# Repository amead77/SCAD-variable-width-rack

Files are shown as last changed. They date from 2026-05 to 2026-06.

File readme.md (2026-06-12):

# Variable width Rack design.

No longer are you stuck with 10" rack or a 19" rack you can't print parts for! What's more, you can actually have supported trays :)

Normal defaults are 350mm wide panel, 330mm deep tray. (this can be changed)

So, what is this actually?
Simply put, I wanted a bigger rack that I could print on my Creality K2plus (350x350x350 build volume) and I wanted it to be 100% in OpenSCAD. Because that's the only software I can use. Fusion 360 is good, but eats cpu, doesn't work on Linux, and worst of all, they changed the licence and features available for hobbyists.
What about FreeCAD? Yeah, FreeCAD is getting good now, but I just didn't want to learn it, because that would require starting out with the spec nailed down before even creating a design. It wasn't at the start.

One of the biggest reasons for creating it was also anger. I printed the parts for a 10" mini rack because I was prepared to make do. But the design was such that to remove a tray, you need to dismantle the whole thing, because of the way the trays are secured at the rear.

There is a picture of the mini-rack that made me angry at the bottom of this readme.

Anyway, if you like the design, you're welcome to buy me a coffee:

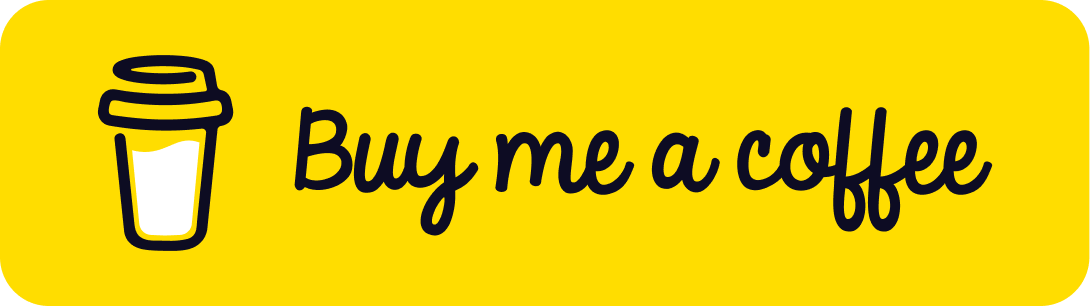
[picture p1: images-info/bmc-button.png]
Buy Me a Coffee


A quick overview

Below is a screenshot of OpenSCAD with a assembly view. This is just to show an example of some of what is possible. Everything is customisable.

## For API reference see [functions.md](functions.md)

I've numbered some arrows so you can see:

1. is showing top header, this is an extra hole added to the post for joining to 2. These  are not required if you don't want stability.
2. is the top join, this joins the posts together at the top. Note: you can have 4 OR MORE posts. I have 6 in this example and how I use it. They can optionally (recommended) have the support cones. This is so the posts can lock in place if they also have cones.
3. A half U panel. Technically not half-U, but that's what I called it. This is used to span across the posts and secure the top and bottom joins.
4. The bottom join. Just like the top.
5. Here is where you put post joins. These are a little square section that joins the inner posts to the top/bottom joins. Otherwise they'd be floating.
6. A side panel. In my case I made a honeycome panel and added a raspberry pi logo.

Note: For mine I used 6 posts (great for half depth trays), 4 face forward, rear 2 face backwards. Consider this when creating posts for which side you want the side-slides on.

2026-06-08: For ease of printing, I've modified:
- Tray design to default to single support rail per-U, as in practice 3 per-U was overkill.
- Split tray into a panel and tray actual, with a joining part added to both with screw holes. I just shoved normal wood screws in mine as that's what I had. (heated them first, so they bind in when cooled)
- Increased the tolerances as in practice printing in different directions with/without support has an effect.

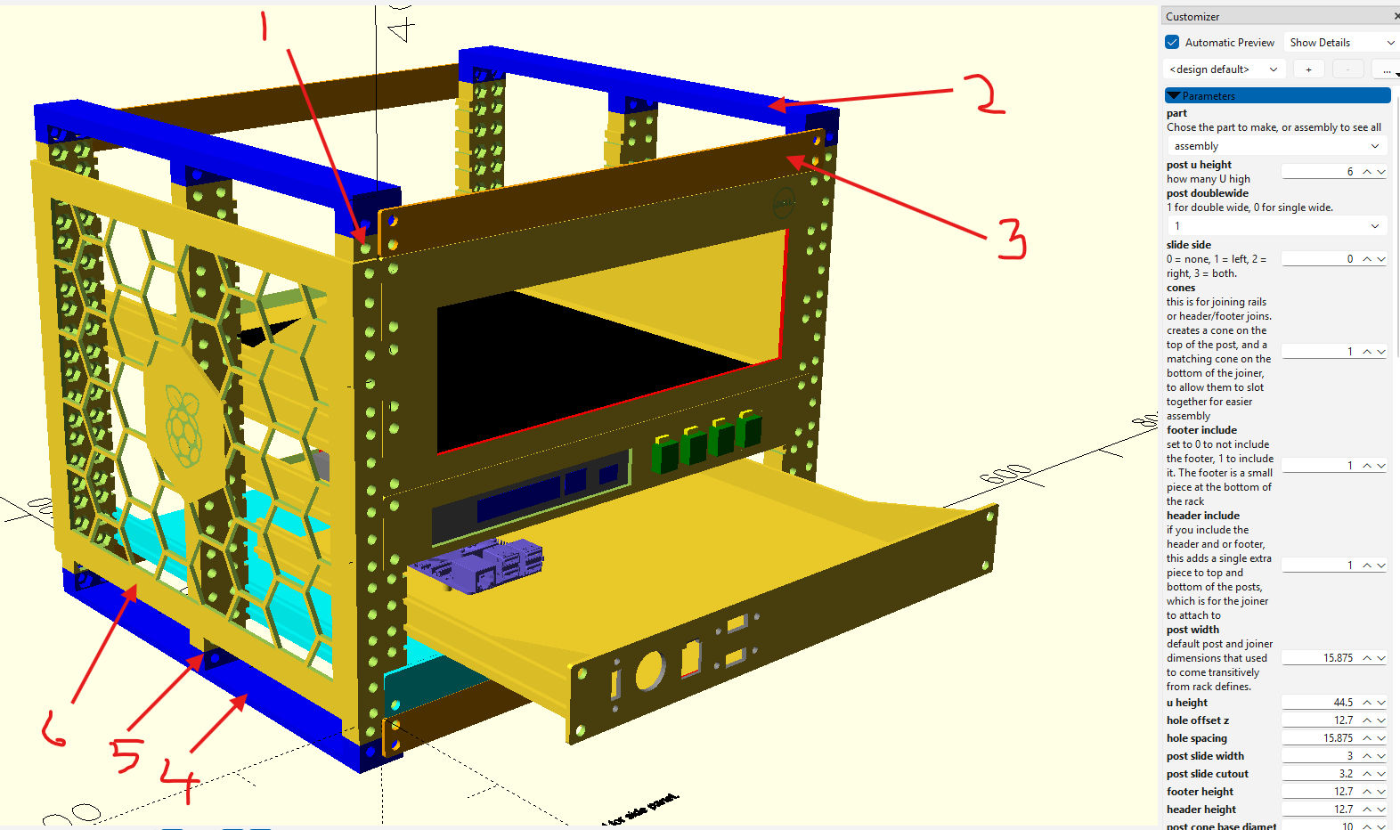
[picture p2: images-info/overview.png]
Assembly overview


Rear view

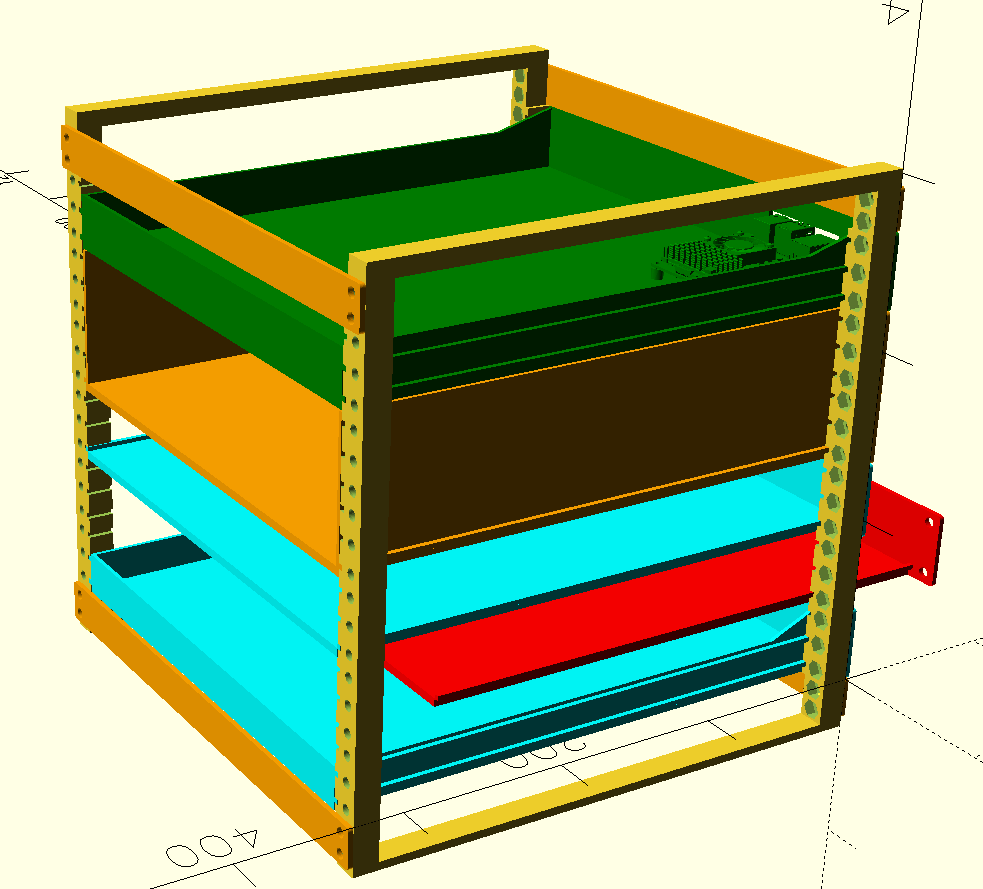
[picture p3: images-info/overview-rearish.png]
Rear view of assembly


8 legged freak

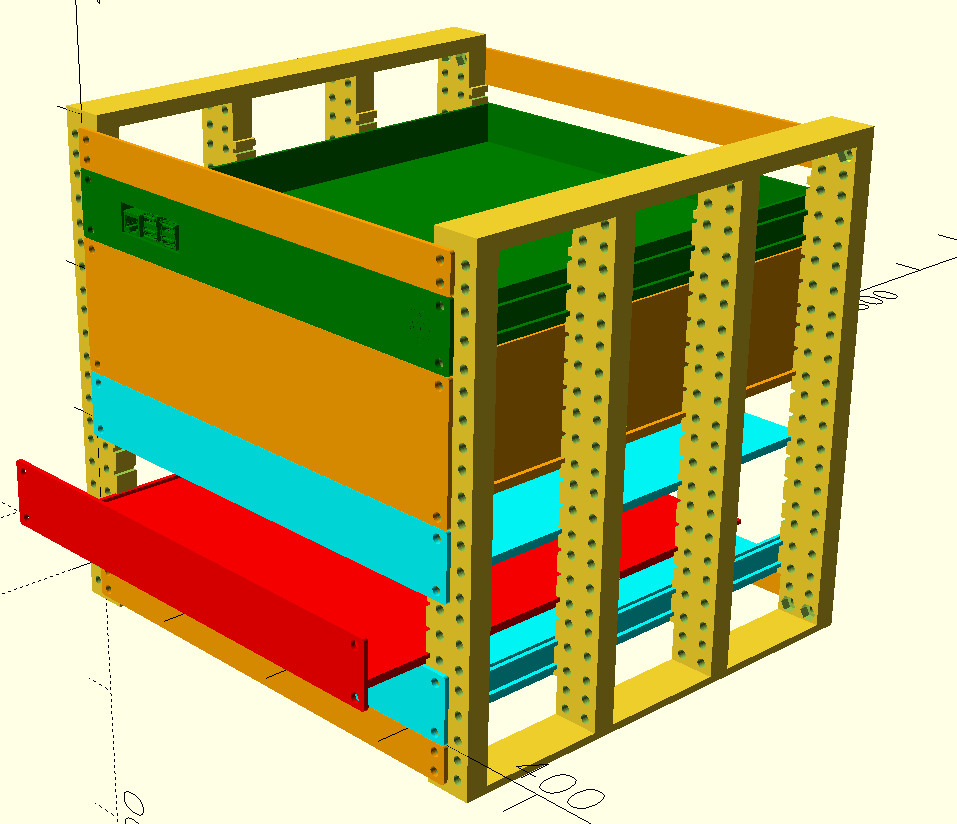
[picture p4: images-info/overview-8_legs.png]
Assembly with 8 legs


How about a part complete rack, as in.. mine. I do have a tray for the Dell, but haven't printed it yet, so the Dell is just thrown in there. It is not a good computer, it is old but it was free.

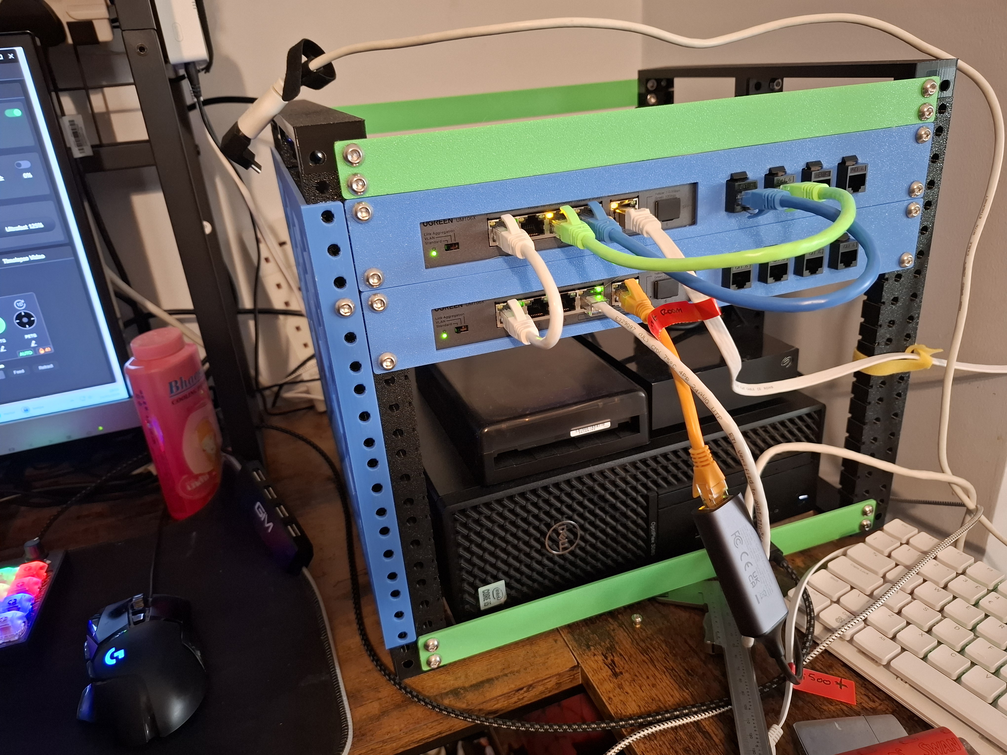
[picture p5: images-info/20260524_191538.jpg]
dell


Now the side panel. You don't have to have honeycomb, you can have a few different designs, plus size of shapes, image/logo is also optional. I have a RPi logo because I have a bunch of them. They'll end up in the rack in due course.

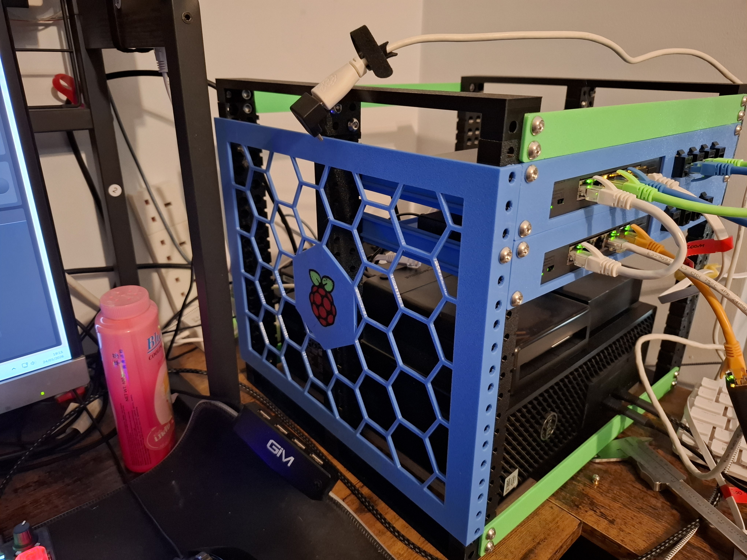
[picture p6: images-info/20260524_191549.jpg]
side panel


---

## Design Goals

- **Rear-slide tray support** — trays slide into a slot in the rear post rather than bolting front and rear. This means trays can be removed without dismantling the rack. This was my biggest gripe with the 10" rack designs.
- **Fully parametric** — all dimensions, hole counts, heights and clearances are driven by variables. Use the OpenSCAD Customizer to configure parts without editing code.
- **Modular** — mix single/double-wide posts, variable-height trays and panels, and optional joiners.

---

## Parts

### Posts

Posts are the vertical rails of the rack. They are generated in configurable U heights and can be single or double wide. A slide channel can be added to the left side, right side, both sides, or neither. 
I highly recommend creating with top/bottom headers, double-wide, cones and side slides. 

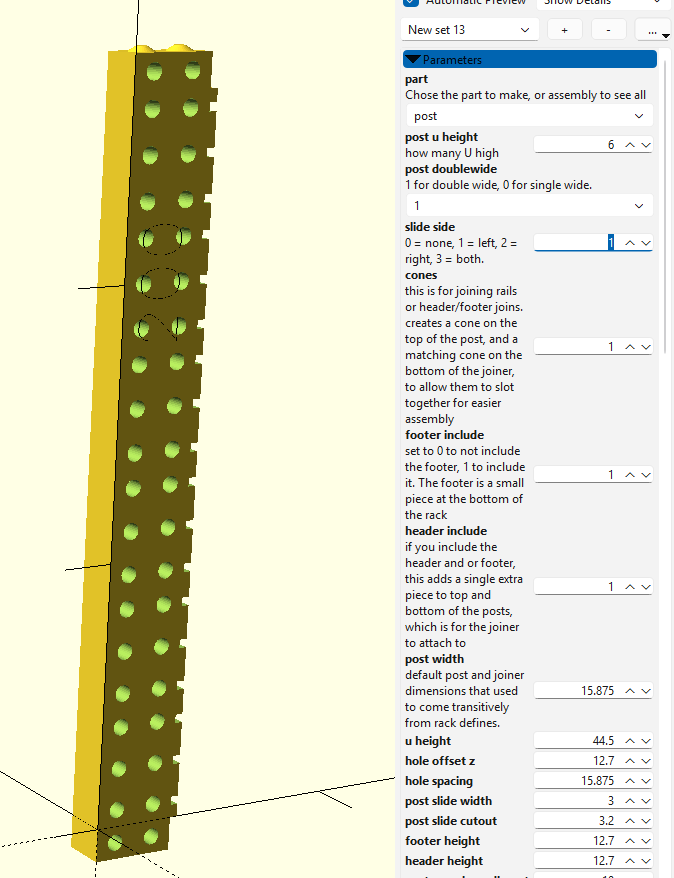
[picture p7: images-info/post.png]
Post


### Trays

Trays are available in fully variable size. The variable tray accepts a `tray_back_panel` flag to add a rear panel, turning it into a drawer. Trays slide into the post's rear slot for easy removal. Trays also don't need to be full length, defining 0.25 will make a quarter depth tray (y axis)

Look at "parts/blank variable tray.scad" to find the tray code, but "parts-optional/intel dg45fg.scad" shows it being used.
More info on how to use later.

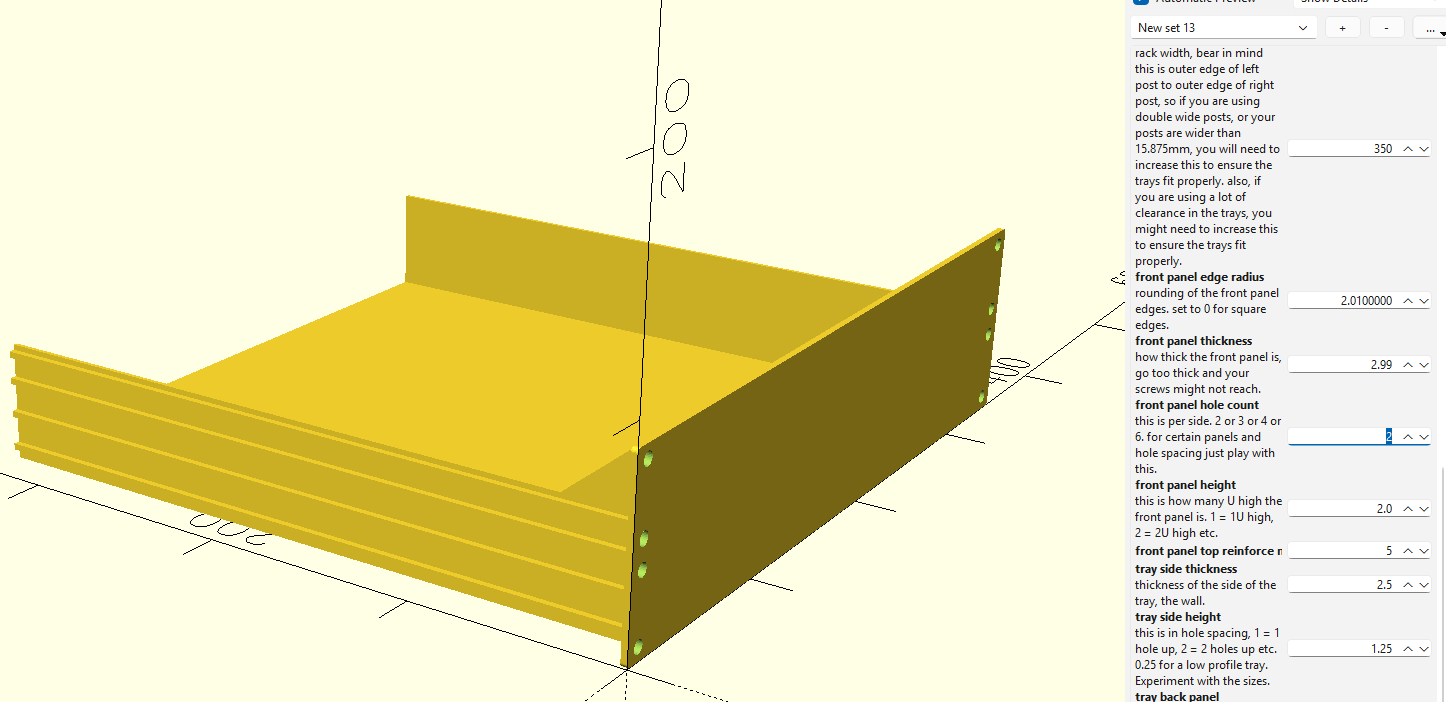
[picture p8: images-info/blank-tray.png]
Variable tray


You can also split the trays for easier printing.

ts1

ts2

ts3

### Panels (Blanking Panels)

"parts/rack panels.scad"

Flat front panels for blanking unused rack slots. Available in ½U, 1U, 2U.
Note that "blank variable tray" can now do all of this apart from the half-U. It is also the recommended method as you can customise it, reinforce, etc.

The half-U for joining posts together when using headers.

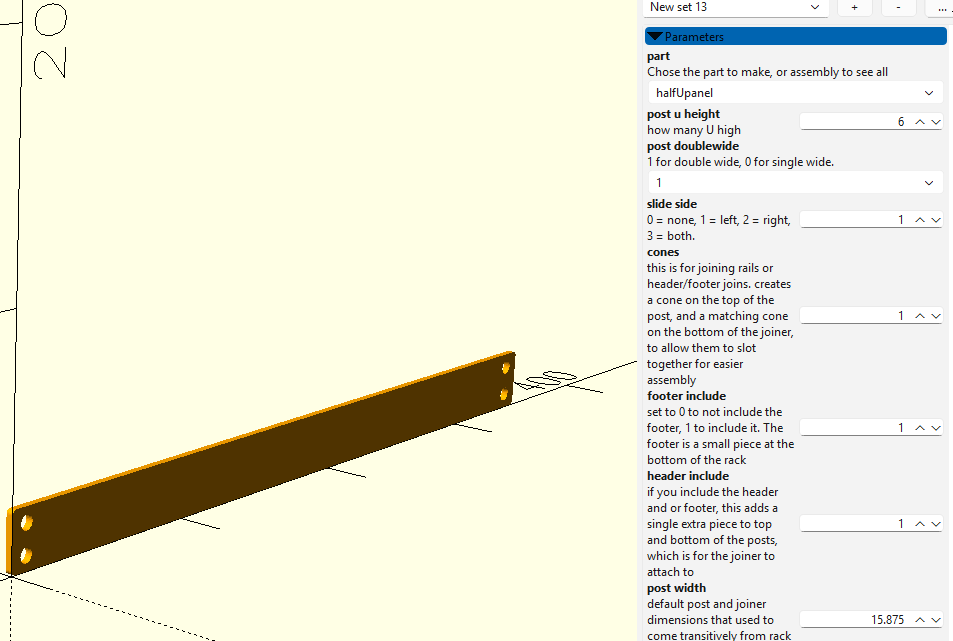
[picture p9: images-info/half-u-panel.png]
Half-U panel


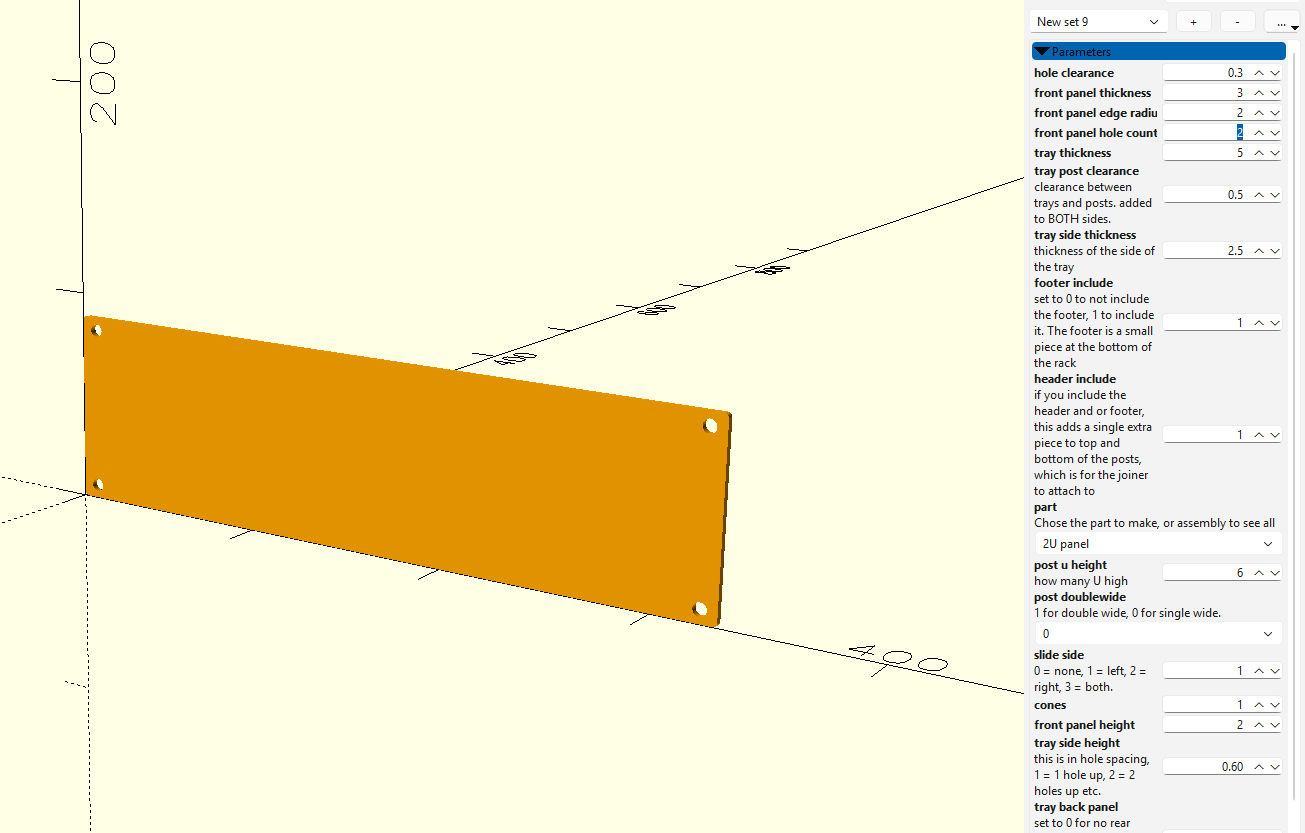
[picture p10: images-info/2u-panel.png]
2U panel


### Footer / Header

Optional pieces added to the top and bottom of POSTS. They provide an attachment point for the joiners.
If you want the front to rear support braces, I recommend adding these on.

### Joiners (Base / Top)

Optional horizontal joiners that connect the front posts to the rear posts via the footer/header. 
You can have more than just 4 posts. The joiners can have 2+ supports, by increasing the number and printing more posts, you can have greater supports

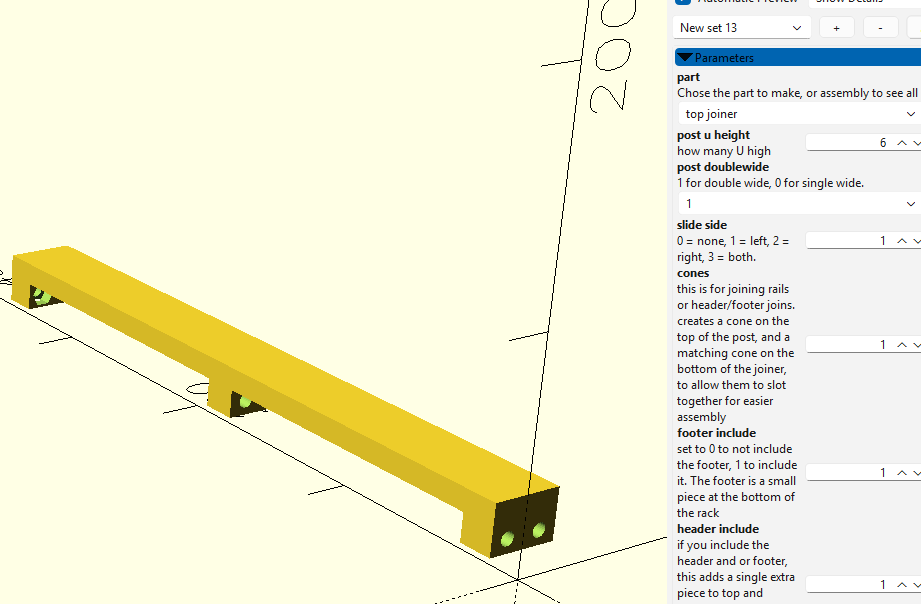
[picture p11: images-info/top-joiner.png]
Top joiner


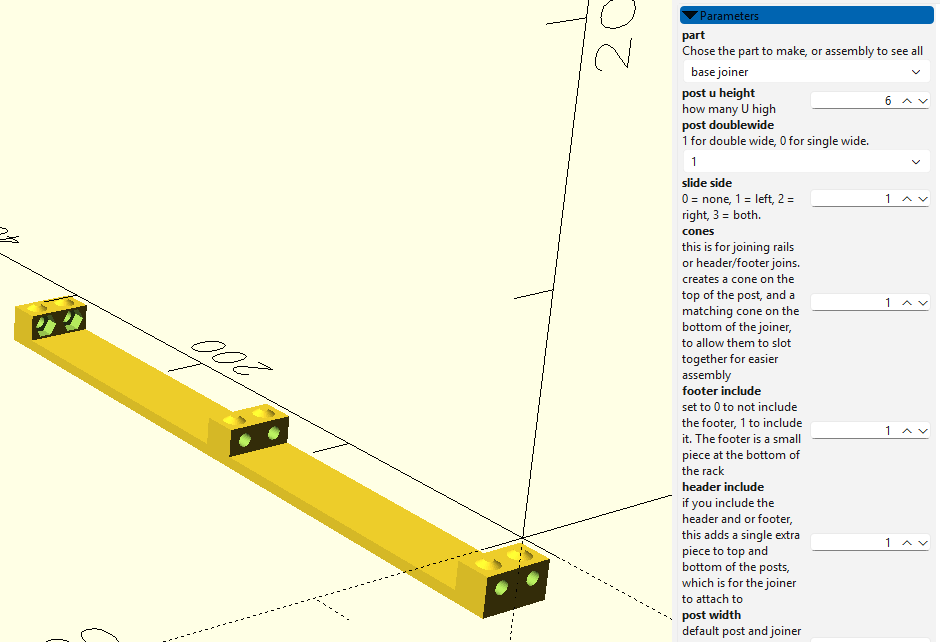
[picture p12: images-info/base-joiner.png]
Base joiner


---

## Custom Trays

The file "parts-optional/intel dg45fg.scad" has a tray I've made for my mini-itx board. Yes it's an older board, this is because I want it for WinXP.
Anyway, it has:
- mount for a FlexATX PSU
- screw holes for mini-itx, for the back panel to be on the rear. (screw holes are sized for my heat-inserts)
- a LED hole in the front for hdd activity
- a Power button (large round) cutout
- Name of board/cpu inside on the front of the panel. (I use a engrave of 0.01mm, this makes it easy to 'paint' in my slicer, while still being level with the panel)
- reinforced front panel at the top
- reinforced rear, by creating a back panel, then chamfering it at 30deg. this is because I print panel face down and it means far less supports
- If my printer wasn't being a D. I'd have it printed by now. 

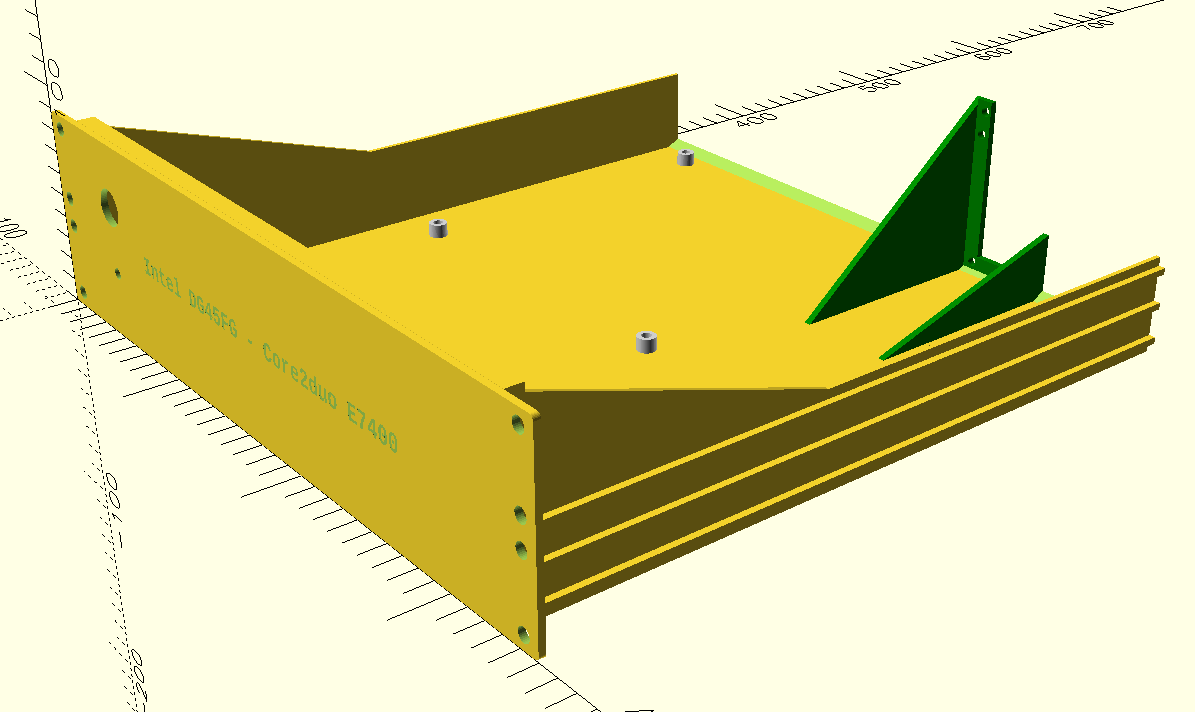
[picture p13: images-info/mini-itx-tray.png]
mini-itx


This picture is the mini-itx tray, but I chopped it to a tiny piece in the slicer, I highly recommend making test pieces before commiting to 12hour+ prints. Even create 1U post with sliders and a part tray to check clearances. Everyone's printer is different.

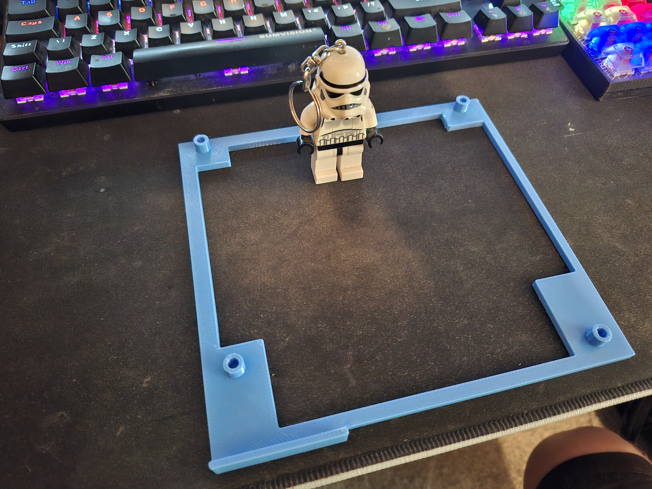
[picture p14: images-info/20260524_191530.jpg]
test print


When I fix my printer I will print the mini-itx tray like the following picture, note that:
- I chop out parts to reduce filament usage. I do the chopping in the slicer by adding negative volumes.
- angle the cutouts so they don't require supports.
- print face down so the support rails don't require supports.
- print face down so my text on the front panel gets printed in one hit on a single layer, rather than changing filament many many times.
- created a back panel, but only small and use a 30 degree chamfer. This is to create a reinforcement that doesn't require supports to print
- Doing it this way means only the PSU mount and mini-itx screw holes need supports.

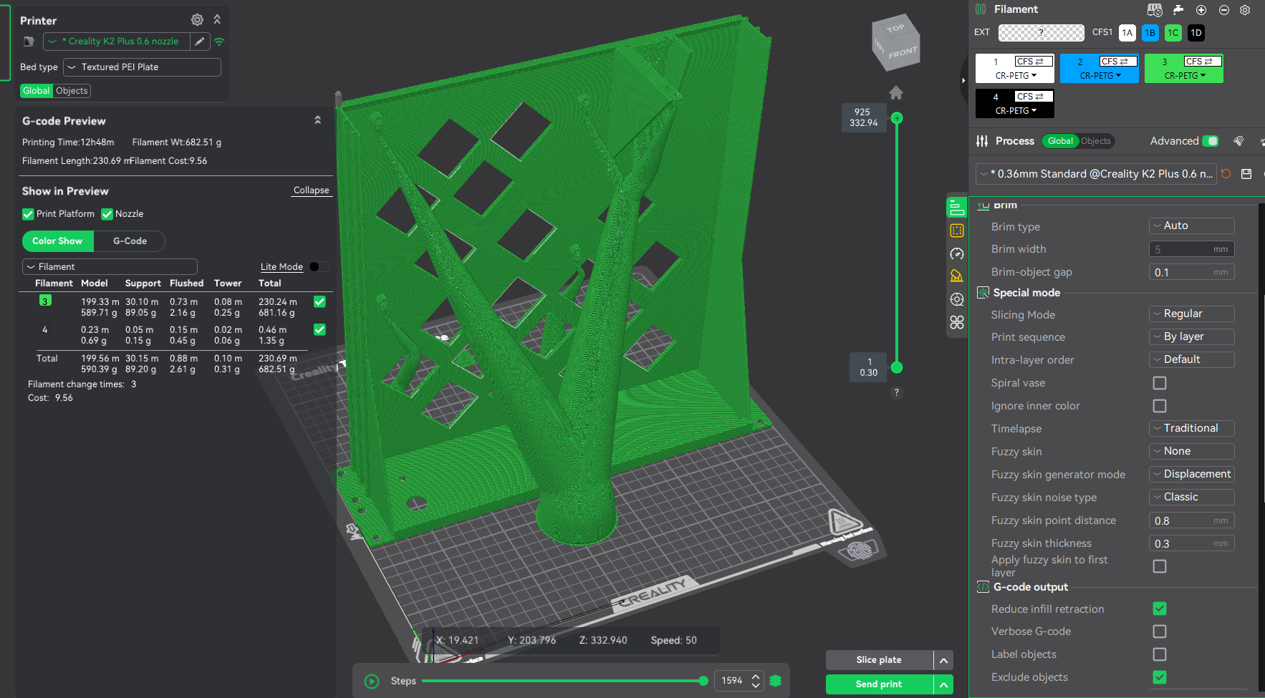
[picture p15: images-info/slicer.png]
slicer


The file "parts-optional/ugreen um106x.scad" is another one I use (x2), and have a photo of in use.
This was created to:
- have my 5 port switch
- 4x keystones

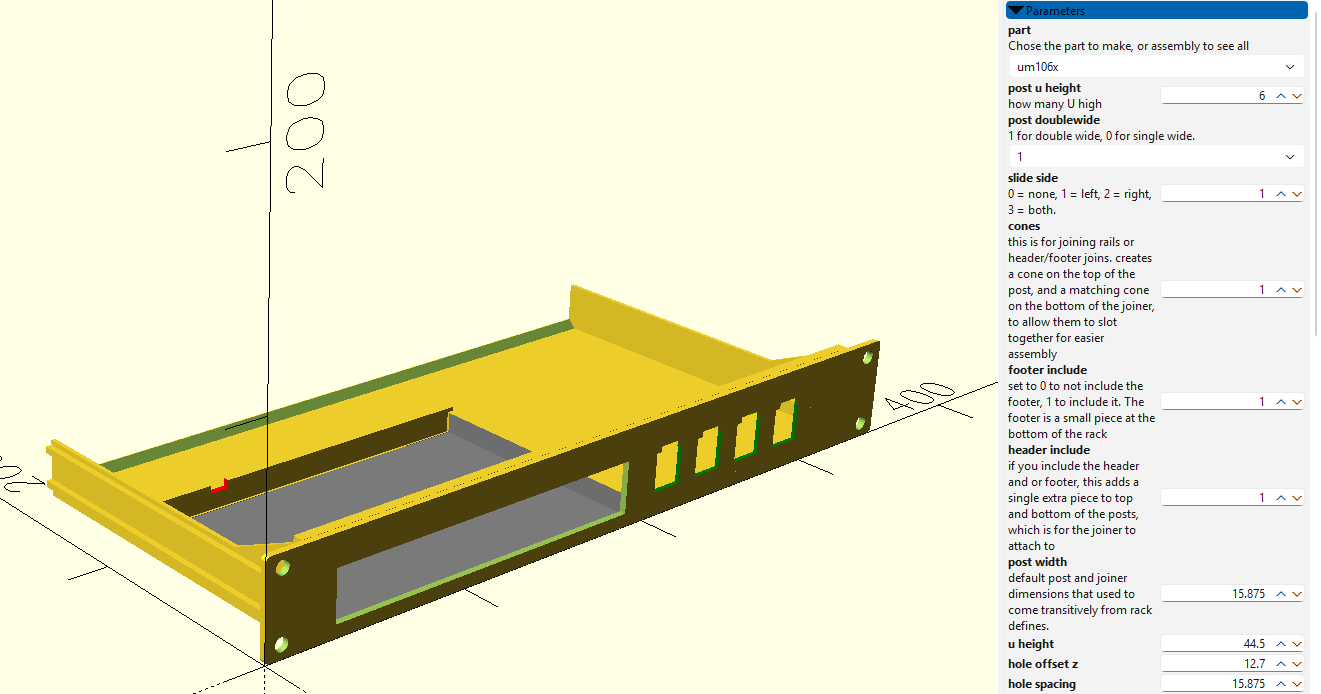
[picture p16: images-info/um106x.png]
ugreen


---

## Usage

1. Open `rack parts.scad` in OpenSCAD. This is not perfect. This will create the basic parts, but not highly customised trays.
2. Open the **Customizer** panel (Window → Customizer).
3. Select the part you want from the `part` dropdown:
   - `assembly` — preview all parts together
   - `post` — a single post, I recommend double-wide for future side panels etc, and slide_sides, if you want the trays to be supported.
   - `base joiner` / `top joiner` — horizontal joiners, also recommended. Make sure your posts have headers/footers and cones.
   - `1U tray` / `2U tray` / `variable tray` — trays
   - `halfUpanel` / `1U panel` / `2U panel` / `variable panel` — blanking panels
4. Adjust the parameters to suit your needs.
5. Render (F6) and export to STL or 3MF

### Key Parameters

| Parameter | Description |
|---|---|
| `post_u_height` | Height of the post in U units |
| `post_doublewide` | `0` = single wide, `1` = double wide |
| `slide_side` | `0` none, `1` left, `2` right, `3` both |
| `front_panel_height` | Panel/tray height in U (can be fractional, e.g. `1.5`) |
| `front_panel_hole_count` | Mounting holes per side (2, 3, 4, or 6) |
| `tray_side_height` | Tray side wall height in hole spacings |
| `tray_back_panel` | `0` = open tray, `1` = drawer with rear panel |
| `footer_include` / `header_include` | Include footer/header attachment pieces |

### Hardware

The design is based on **M6 screws** with **M6 hex nuts** (10mm across-flats, 5mm thick). Adjust `hole_clearance`, `hole_d`, `nut_diameter`, and `nut_thickness` if you want to use different fasteners. See the comments in the posts and trays functions.

---

## File Structure

| File | Purpose |
|---|---|
| `rack parts.scad` | Main entry point — select and configure parts here |
| `parts/rack defines.scad` | All default dimensions and constants - DEPRECIATED, kept for reference|
| `parts/rack posts.scad` | Post geometry |
| `parts/rack panels.scad` | Panel geometry, for 0.5U, 1U and 2U |
| `parts-optional/intel dg45fg.scad` | My mini itx tray, useful for reference
| `parts/blank variable tray.scad` | The main tray and panel making scad. Call blank_variable_tray() for everything, then customise.
---

The reason parts/rack defines.scad is depreciated is because everything got refactored so that the default values of calling the functions are what was in the defines. Everything can be overriden in the function calls.
I really recommend having a look at the parts and how they are called, then look at the function/module they call, because I have commented all the options.

## Requirements

- [OpenSCAD](https://openscad.org/) the releases are ancient, use the nightlies instead. On raspberry pi you have to compile from source.
- A printer that can handle the size you want (e.g. Creality K2 Plus can do 350mm, Prusa XL can do 340mm)

---

## License

This project is licensed under **Creative Commons - Attribution - Non-Commercial (CC BY-NC)**

&copy; 2026 Adam Mead

All images of Raspberry Pi and Dell logos are their own. I have only included to prevent non existent file errors.

## THIS PIC IS NOT MY DESIGN, but I did print it and this is what it produced. It is the reason I made my design:

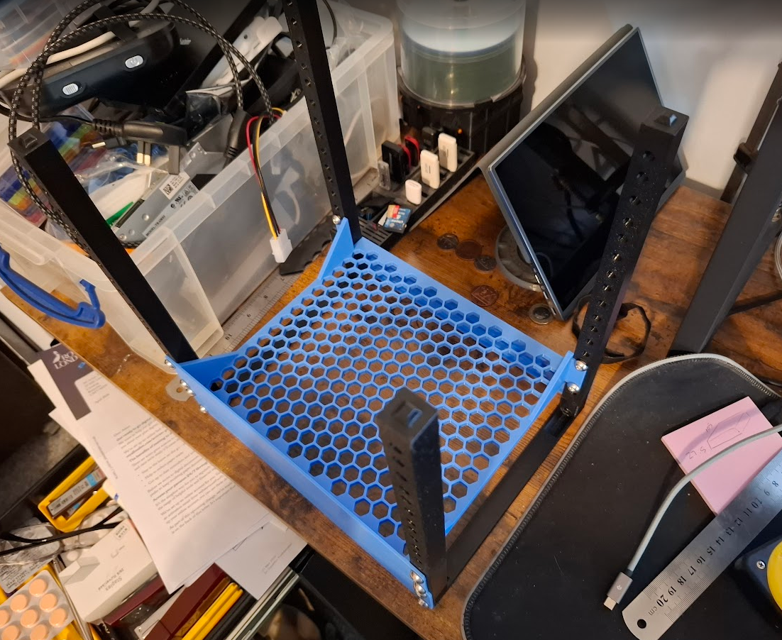
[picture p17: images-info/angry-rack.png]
angry rack


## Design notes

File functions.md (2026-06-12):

# Variable width Rack (default=350mm wide, 330mm deep) - Current Public Module Reference

This file documents the current public callable modules in the four core source files that are enough to build a working rack:

- `parts/rack posts.scad`
- `parts/rack panels.scad`
- `parts/rack side panel.scad`
- `parts/blank variable tray.scad`

If you are building a rack from scratch, the core structural parts are usually:

- `rail_1u_holes()` for posts
- `base_joiner()` for front-to-rear joiners
- `blank_05U_front_panel()` for the front and rear, top and bottom bridging panels - headers/footers to joiners
- `post_base_join_panel()` if you are using extra intermediate posts

Then add either:

- `blank_1U_front_panel()` / `blank_2U_front_panel()` / `blank_variable_tray(mode="panel")` for blanking panels
- `blank_variable_tray()` for trays
- `side_panel()` for optional side panels, adds +5 HP

---

## `parts/rack posts.scad`

### `rail_1u_holes()` - Complete rack post

Builds a complete rack post from stacked 1U sections, including screw holes, rear nut traps, optional slide rails, optional footer/header blocks, and optional alignment cones.

```scad
module rail_1u_holes(
    slide_side,                             // 0 = none, 1 = left, 2 = right, 3 = both side rails.
    doublewide = 0,                         // 0 = single-width post, 1 = double-width post.
    post_height = 3,                        // Post height in U units.
    v_post_cones = 1,                       // 1 = add top cones and bottom sockets, 0 = no cones.
    include_footer = 1,                     // 1 = include the lower footer block.
    include_header = 1,                     // 1 = include the upper header block.
    post_width = 15.875,                    // Width/depth of one post section.
    u_height = 44.5,                        // Height of one U section in mm.
    hole_d = 6.3,                           // Diameter of the post mounting holes.
    hole_offset_z = 12.7,                   // Height from the bottom of a 1U segment to the first hole centre.
    hole_spacing = 15.875,                  // Vertical spacing between hole centres within a 1U segment.
    nut_thickness = 6.3,                    // Depth of the rear nut traps.
    nut_diameter_across_flats = 10.3,       // Across-flats size of the hex nut trap.
    post_slide_width = 2.8,                 // Width of the side slide rail.
    post_slide_cutout = 3.6,                // Size of the slide cutouts in each 1U section.
    footer_height = 12.7,                   // Height of the optional footer block.
    header_height = 12.7,                   // Height of the optional header block.
    post_cone_base_diameter = 10.0,         // Diameter at the base of the alignment cone/socket.
    post_cone_top_diameter = 4.0,           // Diameter at the tip of the alignment cone/socket.
    post_cone_height = 2.0,                 // Height/depth of the alignment cone/socket.
    post_top_cone_clearance = 0.1           // Clearance applied so cones fit into sockets.
)
```

Examples:

```scad
rail_1u_holes(slide_side = 1, post_height = 6);
rail_1u_holes(slide_side = 3, doublewide = 1, post_height = 6, v_post_cones = 1);
```

### `base_joiner()` - Front-to-rear joiner

Builds the horizontal joiner that connects front and rear posts. Set `bottom=1` for the lower joiner and `bottom=0` for the upper joiner.

```scad
module base_joiner(
    doublewide = 0,                         // 0 = single-width post mount, 1 = double-width post mount.
    bottom = 1,                             // 1 = bottom/base joiner, 0 = top/header joiner.
    supports = 2,                           // Number of support positions along the joiner, minimum 2.
    beam_thickness = 5.0,                   // Thickness of the long beam that ties the support blocks together.
    post_width = 15.875,                    // Width of one post footprint.
    rack_width = 330,                       // Front-to-rear span used for the main joiner body layout.
    rack_depth = 330,                       // Front-to-rear span used by the mirrored top joiner cone cut positions.
    footer_height = 12.7,                   // Height of the footer-side mounting blocks.
    header_height = 12.7,                   // Height of the header-side mounting blocks or cone sockets.
    hole_offset_z = 12.7,                   // Vertical position of the joiner mounting hole centre.
    hole_d = 6.3,                           // Diameter of the joiner mounting screw holes.
    nut_thickness = 6.3,                    // Depth of the nut traps for the mounting fasteners.
    nut_diameter_across_flats = 10.3,       // Across-flats size of the hex nut trap.
    post_cone_base_diameter = 10.0,         // Diameter at the base of the alignment cone/socket.
    post_cone_top_diameter = 4.0,           // Diameter at the tip of the alignment cone/socket.
    post_cone_height = 2.0,                 // Height/depth of the alignment cone/socket.
    post_top_cone_clearance = 0.1           // Clearance applied so cones fit into sockets.
)
```

Examples:

```scad
base_joiner();
base_joiner(bottom = 0, beam_thickness = 10.0);
base_joiner(doublewide = 1, supports = 3, beam_thickness = 6.0);
```

---

## `parts/rack panels.scad`

### `blank_1U_front_panel()` - Fixed 1U blanking panel

Builds a standard 1U front blanking panel with the normal rack hole pattern.
*Variable tray* can also built panels and is the *recommended method*, as there are far more options avaiable

```scad
module blank_1U_front_panel(
    holes = 2,                              // Number of mounting holes per side: typically 2, 3, 4, or 6.
    rack_width = 350,                       // Overall panel width across the rack.
    post_width = 15.875,                    // Width of one rack post used to place mounting holes.
    u_height = 44.5,                        // Height of one rack unit in mm.
    front_panel_thickness = 3.0,            // Thickness of the panel face.
    front_panel_undersizing = 0.1,          // Clearance trimmed from panel edges for fit.
    front_panel_edge_radius = 2.0,          // Corner radius for the panel; 0 gives square corners.
    hole_d = 6.3,                           // Diameter of the mounting holes.
    hole_offset_z = 12.7,                   // Height from the bottom to the first hole centre.
    hole_spacing = 15.875                   // Vertical spacing between hole centres.
)
```

### `blank_2U_front_panel()` - Fixed 2U blanking panel

Builds a standard 2U front blanking panel. As above.

```scad
module blank_2U_front_panel(
    holes = 4,                              // Number of mounting holes per side: typically 2, 4, or 6 for 2U.
    rack_width = 350,                       // Overall panel width across the rack.
    post_width = 15.875,                    // Width of one rack post used to place mounting holes.
    u_height = 44.5,                        // Height of one rack unit in mm.
    front_panel_thickness = 3.0,            // Thickness of the panel face.
    front_panel_undersizing = 0.1,          // Clearance trimmed from panel edges for fit.
    front_panel_edge_radius = 2.0,          // Corner radius for the panel; 0 gives square corners.
    hole_d = 6.3,                           // Diameter of the mounting holes.
    hole_offset_z = 12.7,                   // Height from the bottom to the first hole centre.
    hole_spacing = 15.875                   // Vertical spacing between hole centres.
)
```

### `blank_05U_front_panel()` - Top/bottom bridging panel

Builds the short panel used to bridge between posts and the base/header parts. This is not a normal half-U rack panel; it is sized from the rack hole spacing.
This *cannot* currently be built by blank_variable_tray()

```scad
module blank_05U_front_panel(
    rack_width = 350,                       // Overall panel width across the rack.
    post_width = 15.875,                    // Width of one rack post used to place mounting holes.
    front_panel_thickness = 3.0,            // Thickness of the panel face.
    front_panel_undersizing = 0.1,          // Clearance trimmed from panel edges for fit.
    front_panel_edge_radius = 2.0,          // Corner radius for the panel; 0 gives square corners.
    hole_d = 6.3,                           // Diameter of the mounting holes.
    hole_offset_z = 12.7                    // Half-U hole offset used to derive the fixed panel height and hole positions.

)
```

### `post_base_join_panel()` - Post-to-joiner connector panel

Create a compact rectangular join panel used to fasten a post footprint to abase or top joiner support position. It can be generated for either a single-width or double-width post footprint.
You only need this if you have internal posts (e.g. more than 4 posts)
Calling with just post_base_join_panel(); will produce the default single-width
join panel.

```scad
module post_base_join_panel(
    doublewide = 0,                         // 0 = single-width post footprint, 1 = double-width post footprint.
    thickness = 3.0,                        // Thickness of the join panel.
    post_width = 15.875,                    // Width of one rack post footprint.
    hole_offset_z = 12.7,                   // Height from the bottom to the first hole centre.
    hole_d = 6.3                            // Diameter of the panel mounting holes.
)
```

---

## `parts/blank variable tray.scad`

### `blank_variable_front_panel()` - Variable-height front panel

Builds a variable-height front panel with optional text, optional imported artwork, and optional reinforcement lips.
Avoid using this directly, use blank_variable_tray() with mode="panel"
That way you get all the options.

### `blank_variable_tray()` - Variable tray or variable panel

Builds either a tray or a panel using the same front-panel geometry. This is the preferred module for most new trays and custom panels. Can also create a tray/panel split, so you can print both parts and screw together.

```scad
module blank_variable_tray(
    mode                    = "tray", //"tray", "panel", "split_panel_show", "split_panel_tray", "split_panel_panel"
    panel_u_size            = 1, // front panel height in U
    front_panel_top_reinforce_mm     = 0, //a reinforcing lip at the top of the panel
    front_panel_bottom_reinforce_mm  = 0, //same but bottom. these are on the back of the panel
    tray_u_size             = undef, // side/base height in U. if undef, defaults to panel_u_size. if 0.6 is used, you can get 2 slides per side, 0.5 would only make the sides high enough for 1 slide
    tray_depth_scale        = 1, // 0 to 1, fraction of rack_width. 1 = full rack_width depth (330mm), 0.5 = rack_width/2 depth (165mm), etc.
    holes                   = 2, // mounting holes PER SIDE (2, 3, 4, or 6). I need to revisit this, as '2' would put 4 holes in each side of a 2U panel, but you might only want 2 each side (top/bottom)
    import_file             = "", //used for importing an SVG or STL/3MF onto the front panel face, see variable_front_panel_face_import() parameters below.
    import_type             = "none", //"svg", "stl", or "none"
    import_width            = 0, //if 0, defaults to 50% of the front panel inner width. used for imported SVGs and STLs/3MFs.
    import_height           = 0, //if 0, defaults to 50% of the front panel inner height. used for imported SVGs and STLs/3MFs.
    import_depth            = 0.8, //how far the imported design is embossed (positive) or engraved (negative). if 0, defaults to 0.8mm for SVGs, and 50% of the target width for STLs/3MFs.
    import_offset_x         = 0, //X offset for imported design from exact center of front panel. positive values move right, negative values move left.
    import_offset_z         = 0, //Z offset for imported design from exact center of front panel. positive values move up, negative values move down.
    import_mode             = "emboss", // "emboss" (raised from front face) or "engrave" (cut into front face)
    panel_text              = "", //optional text to add to the front panel
    panel_text_font         = "Liberation Mono:style=Bold", //font for the panel text, using the format "FontName:style=Style". you can use any font installed on your system, and specify the style if needed. check the OpenSCAD documentation for details on font naming and styles.
    panel_text_size         = 10, //font size for the panel text
    panel_text_depth        = 0.8, //depth for engraving the panel text. ignored if panel_text is empty.
    panel_text_offset_x     = 0, //X offset for panel text from exact center. positive values move right, negative values move left.
    panel_text_offset_z     = 0, //Z offset for panel text from exact center. positive values move up, negative values move down.
    panel_text_mode         = "engrave", // "emboss" or "engrave" for the panel text
    side_support            = 1, //0 or 1 to add gussets between front panel and sides when panel is taller than sides
    side_support_back       = 40, //how far back the gussets extend (mm)
    side_support_thickness  = 2.0, //normally the same as tray_side_thickness, but can be different if you want thinner gussets
    side_support_single     = true, // if true, only add a single side support rail per-U, at the lowest position.
    tray_side_thickness     = 2.0, //thickness of the tray side walls in mm.
    front_panel_thickness   = 3.0, //consider your screw lengths. 3mm is usually fine for m6x16 screws.
    back_panel              = 0, //0 or 1 to add a rear wall to make a drawer. rear wall height controlled by back_panel_height (in U).
    back_panel_thickness    = 2.0, //the rear wall thickness, if you have back_panel=1.
    back_panel_height       = 1.0, //in U units, converted to mm internally
    back_panel_chamfer      = 0.0, //mm front edge chamfer on the rear wall. primary purpose is for printing overhang angle reduction.
    back_panel_chamfer_ang  = 45.0, //degrees for the rear wall chamfer angle. 45 degrees is a good starting point, but you can adjust as needed. this is only used if back_panel_chamfer > 0.
    tray_thickness          = 5.0, //thickness of the tray base in mm.
    rack_width              = 350, //this is the external width of the rack, if single-width, using this and post_width is what determines the panel and tray widths and depths.
    rack_depth              = 330, //this can be different than the width
    post_width              = 15.875, //a normal single-width rack. If using double-width and/or sliders, this will be wider, but calculated automatically based on this.
    hole_d                  = 6.4, //holes sized for m6 screws, but slightly oversized for clearance.
    u_height                = 44.5, //standard U height in mm.
    hole_offset_z           = 12.7, //initial hole offset from the bottom panel/rack post in mm.
    hole_spacing            = 15.875, //spacing between holes in mm, standard U spacing.
    front_panel_undersizing = 0.1, //mm the front panel is undersized by on each edge to ensure it doesn't interfere with other panels
    front_panel_edge_radius = 2.0, //mm radius for front panel edges. set to 0 for sharp edges.
    tray_post_clearance     = 0.6, //0.5mm clearance, this makes 1mm total tray clearance. adjust as needed. modifying this might require tweaking the post_slide_cutout and hole_clearance to ensure the holes still clear properly.
    tray_side_slides        = 1,   //0 or 1 to add side slides that go into the posts. these are designed to fit into the post 
                                    //cutouts defined by post_slide_cutout/width, so adjust those dimensions if you change the slide design.
    post_slide_width        = 2.8, //*these next 2 are for the slides that go into the posts on the rack.
    post_slide_cutout       = 3.6, //*ideally you should create a 1U post for testing the fit of these before printing everything.
                                   //*you would be better off adjusting the post dimensions, rather than changing the tray dimensions, 
                                   //and create posts to fit the trays. making the side slides smaller to fit would make them weaker. 
                                   //So make the post cutouts bigger instead.
    post_slide_clearance    = 0.4, //clearance for the fit of the tray side slides into the post cutouts. adjust as needed for fit; this is separate from the tray_post_clearance to allow for different clearances on the sides vs the back of the tray if needed.
    hole_clearance          = 0.0, //clearance around the panel holes, for screwing into the posts.
    panel_join_clearance    = 0.3, //clearance for the side parts of the tray to panel join.
    panel_join_thickness    = 5.0, //thickness of the panel joiner.
    panel_join_hole_dia     = 3.5, //diameter of the screw holes for the panel to tray join.
    panel_join_hole_offset_z = 15.875, //offset of the first panel join hole from the bottom of the front panel, in mm.
    panel_join_cs_dia       = 7.0, //countersink the panel join holes on the outer faces.
    panel_join_length       = 15.0, //length of the panel join in the Y direction.
    panel_join_offset_from_edge = 10.0 //distance from the front/back edge of the joiner length to the center of the panel join holes.
) 

```

Examples:

```scad
blank_variable_tray(panel_u_size = 1, tray_u_size = 0.75, holes = 2);
blank_variable_tray(panel_u_size = 1, tray_u_size = 0.75, tray_depth_scale = 0.5, back_panel = 1);
blank_variable_tray(mode = "panel", panel_u_size = 1.5, holes = 2);
blank_variable_tray(panel_u_size = 2, tray_u_size = 1.5, holes = 4, import_file = "../images-logo/raspberry-pi.svg", import_type = "svg", import_mode = "emboss");
```

---

## `parts/rack side panel.scad`

### `side_panel()` - Side panel with optional pattern and logo

Builds a side panel with mounting lips and hole pattern sized to the rack, with optional cutout patterning and an optional logo insert/recess area. TODO: Doesn't currently cover the header/footer, or top/bottom joiner. But does look awesome.

```scad
module side_panel(
    p_cv_panel_u_height = 6,                 // Panel height in U units.
    p_c_u_height = 44.5,                     // Height of 1U in mm.
    p_c_foot_add = 0,                        // Extra height added at the bottom.
    p_c_head_add = 0,                        // Extra height added at the top.
    p_c_panel_oversizing = 0.2,              // Extra depth added to improve fit tolerance.
    p_cv_panel_depth = 330,                  // Main panel depth in mm.
    p_c_panel_thickness = 3,                 // Thickness of the side panel body.
    p_c_lip_thickness = 3,                   // Thickness for the front/rear mounting lips.
    p_c_hole_clearance = 0.2,                // Extra clearance added to screw hole diameter.
    p_cv_post_width = 15.875,                // Rack post width used to size lips and hole positions.
    p_c_hole_offset_z = 12.7,                // Height from the bottom to the first hole centre.
    p_c_hole_spacing = 15.875,               // Vertical spacing between mounting holes.
    p_c_front_panel_edge_radius = 2.0,       // Radius on the lip edge corners.

    p_c_pattern = "honeycomb",              // Pattern type: [none, honeycomb, circles, squares, slots].
    p_c_pattern_margin = 20,                 // Margin from panel edges before the cutout pattern starts.
    p_c_pattern_hole_dia = 20,               // Size of the honeycomb/circle/square openings.
    p_c_pattern_offset_y = 0,                // Pattern offset along the panel depth to fine-tune edge cropping.
    p_c_pattern_offset_z = 0,                // Pattern offset along the panel height to fine-tune edge cropping.
    p_c_pattern_edge_offset_left = 1.3,      // Controls whether depth-side cropping is biased toward the start edge.
    p_c_pattern_edge_offset_bottom = 1,      // Controls whether height-side cropping is biased toward the bottom edge.
    p_c_pattern_grid_layout = "offset",     // [inline, offset] Grid layout for circle/square/slot patterns.
    p_c_pattern_slot_length = 50,            // Slot length when using the slot pattern.
    p_c_pattern_slot_width = 15,             // Slot width when using the slot pattern.
    p_c_pattern_slot_wall = 2,               // Material left between slot openings.
    p_c_pattern_slot_rounded = true,         // Whether slot ends are rounded.
    p_c_pattern_slot_rotation = 45,          // Rotation angle for slots in degrees.

    p_c_side_panel_logo = false,             // Enable the logo insert/pocket feature.
    p_c_side_panel_logo_shape = "hexagon",  // [square, circle, hexagon] Base shape behind the logo.
    p_c_side_panel_logo_rotation = 60,       // Rotation applied to the base logo shape.
    p_c_side_panel_logo_size = 100,          // Overall size of the logo base shape.
    p_c_side_panel_logo_import_file = "",   // Optional imported SVG/PNG/STL/3MF for the logo artwork.
    p_c_side_panel_logo_import_width = 40,   // Target width for the imported logo artwork.
    p_c_side_panel_logo_import_height = 50,  // Target height for the imported logo artwork.
    p_c_side_panel_logo_import_rotation = [0, 0, 90], // Rotation applied to the imported artwork.
    p_c_side_panel_logo_import_ypos = 160,   // Depth position of the imported artwork within the logo shape.
    p_c_side_panel_logo_import_zpos = 135,   // Height position of the imported artwork within the logo shape.
    p_c_side_panel_logo_ypos = -1,           // Logo shape depth position; -1 centers it automatically.
    p_c_side_panel_logo_zpos = -1,           // Logo shape height position; -1 centers it automatically.
    p_c_side_panel_import_mode = "recessed", // [recessed, raised] Whether the imported logo is recessed or raised.
    p_c_side_panel_logo_depth = 1.0          // Depth of the recess or height of the raised logo.
)
```

Example:

```scad
side_panel();
side_panel(p_c_pattern = "slots", p_c_pattern_slot_rotation = 45);
side_panel(
    p_c_pattern_hole_dia = 50,
    p_c_side_panel_logo = true,
    p_c_side_panel_logo_import_file = "../images-logo/raspberry-pi.svg",
    p_c_side_panel_logo_depth = 0.01
);
```

---

## Minimal Working Rack

For the minimum functional rack structure, you typically need:

1. `rail_1u_holes(...)` for the posts
2. `base_joiner(bottom = 1, ...)` for the lower joiners
3. `base_joiner(bottom = 0, ...)` for the upper joiners
4. `blank_05U_front_panel(...)` for the top and bottom bridging panels

If you use more than four posts, also add:

5. `post_base_join_panel(...)` for the intermediate post-to-joiner connections

Then add whichever front panels, trays, and side panels you want:

- Fixed panels: `blank_1U_front_panel()` / `blank_2U_front_panel()`
- Variable panel: `blank_variable_tray(mode = "panel", ...)`
- Variable tray: `blank_variable_tray(...)`
- Side panel: `side_panel(...)`

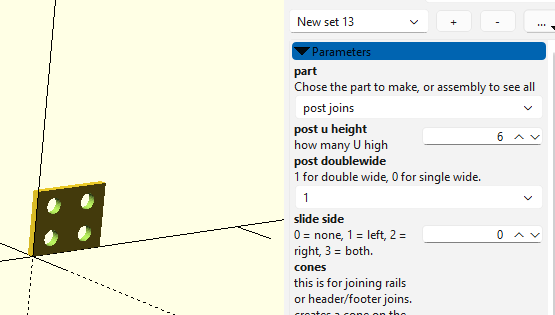
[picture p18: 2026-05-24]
images-info/post-joins.png

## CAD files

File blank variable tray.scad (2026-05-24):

// blank variable tray.scad
// Variable-height front panel and tray modules.
// All rack dimensions are explicit parameters — no external defines file required.
// Default values match the 330mm rack standard (front_panel_thickness=3, rack_width=330, etc.).
//
// Public modules:
//   blank_variable_front_panel(...)  — variable-height blanking front panel
//   blank_variable_tray(...)         — variable-height tray with front panel and side slides
//
// All parameters have sensible defaults so the modules work out of the box for a standard
// 330mm rack, but every dimension can be overridden on the call.


// =============================================================================

//to do
// Panel holes = 2, 
// ** mounting holes PER SIDE (2, 3, 4, or 6).
//
// ** this is defined in the tray and panel function call, but can create undesired hole spacing on >1U panels:
// ** '2' would put 4 holes in each side of a 2U panel, but you might only want 2 each side (top/bottom). This creates holes for EACH U segment.



/*
// next 2 lines used only by my 'on save' script. can be ignored otherwise.
// AUTO-V
version = "v0.1-2026/05/24r05";
*/

function variable_holes_per_u(holes) = (holes >= 6) ? 3 : ((holes >= 4) ? 2 : holes);


// variable_front_panel_hole_at(x_pos, z_pos, post_width, hole_d)
// Subtracts a single screw hole through the front panel at the given X and Z position.
module variable_front_panel_hole_at(
    x_pos,
    z_pos,
    post_width = 15.875,
    hole_d     = 6.3
) {
    translate([x_pos, post_width / 2, z_pos]) {
        rotate([90, 0, 0]) {
            cylinder(d = hole_d, h = post_width, center = true, $fn = 32);
        }
    }
}


// variable_front_panel_holes(panel_height, holes, u_height, hole_offset_z, hole_spacing, post_width, rack_width, hole_d)
// Subtracts the correct pattern of screw holes across a variable-height front panel.
// holes: mounting holes per side (2, 3, 4, or 6).
module variable_front_panel_holes(
    panel_height,
    holes        = 2,
    u_height     = 44.5,
    hole_offset_z = 12.7,
    hole_spacing = 15.875,
    post_width   = 15.875,
    rack_width   = 330,
    hole_d       = 6.3
) {
    holes_per_u    = variable_holes_per_u(holes);
    max_u_segments = ceil(panel_height / u_height);

    for (u_seg = [0 : max_u_segments - 1]) {
        if (holes_per_u >= 1) {
            z1 = (u_seg * u_height) + (hole_offset_z / 2);
            if (z1 <= panel_height - (hole_offset_z / 2) + 0.001) {
                variable_front_panel_hole_at(post_width / 2,             z1, post_width, hole_d);
                variable_front_panel_hole_at(rack_width - post_width / 2, z1, post_width, hole_d);
            }
        }
        if (holes_per_u >= 2) {
            z2 = (u_seg * u_height) + (hole_offset_z / 2) + (hole_spacing * 2);
            if (z2 <= panel_height - (hole_offset_z / 2) + 0.001) {
                variable_front_panel_hole_at(post_width / 2,             z2, post_width, hole_d);
                variable_front_panel_hole_at(rack_width - post_width / 2, z2, post_width, hole_d);
            }
        }
        if (holes_per_u >= 3) {
            z3 = (u_seg * u_height) + (hole_offset_z / 2) + hole_spacing;
            if (z3 <= panel_height - (hole_offset_z / 2) + 0.001) {
                variable_front_panel_hole_at(post_width / 2,             z3, post_width, hole_d);
                variable_front_panel_hole_at(rack_width - post_width / 2, z3, post_width, hole_d);
            }
        }
    }
}


// variable_front_panel_body(panel_height, front_panel_thickness, rack_width, front_panel_undersizing, front_panel_edge_radius)
// Generates the solid panel body at the given height in mm, with optional edge rounding.
module variable_front_panel_body(
    panel_height,
    front_panel_thickness            = 3.0,
    rack_width                       = 330,
    post_width                       = 15.875,
    front_panel_undersizing          = 0.1,
    front_panel_edge_radius          = 2.0,
    front_panel_top_reinforce_mm     = 0,
    front_panel_bottom_reinforce_mm  = 0,
    tray_post_clearance              = 0.5,
    reinforce_x_override             = undef,
    reinforce_w_override             = undef
) {
    reinforce_x_default = post_width + tray_post_clearance;
    reinforce_w_default = rack_width - (2 * reinforce_x_default);
    reinforce_x = is_undef(reinforce_x_override) ? reinforce_x_default : reinforce_x_override;
    reinforce_w = is_undef(reinforce_w_override) ? reinforce_w_default : reinforce_w_override;

    if (front_panel_edge_radius > 0) {
        translate([
            front_panel_undersizing + front_panel_edge_radius,
            0,
            front_panel_undersizing + front_panel_edge_radius
        ]) {
            minkowski() {
                cube([
                    rack_width   - (front_panel_undersizing * 2) - (front_panel_edge_radius * 2),
                    front_panel_thickness,
                    panel_height - (front_panel_undersizing * 2) - (front_panel_edge_radius * 2)
                ]);
                rotate([90, 0, 0]) {
                    cylinder(r = front_panel_edge_radius, h = 0.01, center = true, $fn = 32);
                }
            }
        }
    } else {
        translate([front_panel_undersizing, 0, front_panel_undersizing]) {
            cube([
                rack_width   - (front_panel_undersizing * 2),
                front_panel_thickness,
                panel_height - (front_panel_undersizing * 2)
            ]);
        }
    }

    //top reinforcement lip
    if ((front_panel_top_reinforce_mm > 0) && (reinforce_w > 0)) {
        translate([reinforce_x, front_panel_thickness, panel_height - front_panel_top_reinforce_mm]) {
            cube([reinforce_w, front_panel_top_reinforce_mm, front_panel_top_reinforce_mm]);
        }
    }

    //bottom reinforcement lip
    if ((front_panel_bottom_reinforce_mm > 0) && (reinforce_w > 0)) {
        translate([reinforce_x, front_panel_thickness, 0]) {
            cube([reinforce_w, front_panel_bottom_reinforce_mm, front_panel_bottom_reinforce_mm]);
        }
    }
}


// variable_front_panel_face_import(panel_height, import_file, import_type, import_width, import_height, import_depth, import_offset_x, import_offset_z, import_mode, rack_width, front_panel_undersizing)
// Embosses or engraves an SVG or STL/3MF onto the front panel face.
// import_type: "svg", "stl", or "none". import_mode: "emboss" (raised) or "engrave" (cut in).
// Called by blank_variable_front_panel(); not normally used directly.
module variable_front_panel_face_import(
    panel_height,
    import_file             = "",
    import_type             = "none",
    import_width            = 0,
    import_height           = 0,
    import_depth            = 0.8,
    import_offset_x         = 0,
    import_offset_z         = 0,
    import_mode             = "emboss",
    rack_width              = 330,
    front_panel_undersizing = 0.1
) {
    if ((import_type != "none") && (import_file != "")) {
        panel_inner_width  = rack_width   - (front_panel_undersizing * 2);
        panel_inner_height = panel_height - (front_panel_undersizing * 2);

        target_width  = (import_width  > 0) ? import_width  : panel_inner_width  * 0.5;
        target_height = (import_height > 0) ? import_height : panel_inner_height * 0.5;
        target_depth  = (import_depth  > 0) ? import_depth  : 0.8;

        x_pos = front_panel_undersizing + (panel_inner_width  / 2) + import_offset_x;
        z_pos = front_panel_undersizing + (panel_inner_height / 2) + import_offset_z;
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

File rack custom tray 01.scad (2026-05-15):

include <330mm blank variable tray.scad>;

/*
// next 2 lines used only by my 'on save' script. can be ignored otherwise.
// AUTO-V
version = "v0.1-2026/05/15r00";
*/


// rpi5_io_cutout_left(cutout_x, cutout_z, cutout_w, cutout_h, clearance, front_panel_thickness)
// Internal helper — subtracts a rectangular IO port cutout from the front panel.
module rpi5_io_cutout_left(
    cutout_x = 15.875 + 8,
    cutout_z = 10,
    cutout_w = 56,
    cutout_h = 18,
    clearance = 0.6,
    front_panel_thickness = 3.0
) {
    translate([cutout_x - clearance, -0.5, cutout_z - clearance]) {
        cube([cutout_w + (clearance * 2), front_panel_thickness + 1.0, cutout_h + (clearance * 2)]);
    }
}


// standoff_heat_insert(x, y, z, h, d, insert_d, insert_depth)
// Utility — generates a cylindrical standoff with a heat-set insert bore at the top.
module standoff_heat_insert(
    x,
    y,
    z,
    h = 6,
    d = 7.0,
    insert_d = 3.8,
    insert_depth = 4.5
) {
    difference() {
        translate([x, y, z]) {
            cylinder(h = h, d = d, center = false, $fn = 48);
        }
        translate([x, y, z + h - insert_depth]) {
            cylinder(h = insert_depth + 0.2, d = insert_d, center = false, $fn = 32);
        }
    }
}


// rpi5_standoffs_left(...)
// Utility — places four standoffs in the standard Raspberry Pi 5 mounting hole pattern.
module rpi5_standoffs_left(
    mount_origin_x = 15.875 + 14,
    mount_origin_y = 3.0 + 9,
    hole_dx = 58,
    hole_dy = 49,
    standoff_h = 6,
    standoff_d = 7.0,
    insert_d = 3.8,
    insert_depth = 4.5,
    front_panel_undersizing = 0.1,
    tray_thickness = 5.0
) {
    standoff_z = front_panel_undersizing + tray_thickness;

    standoff_heat_insert(mount_origin_x,           mount_origin_y,           standoff_z, standoff_h, standoff_d, insert_d, insert_depth);
    standoff_heat_insert(mount_origin_x + hole_dx, mount_origin_y,           standoff_z, standoff_h, standoff_d, insert_d, insert_depth);
    standoff_heat_insert(mount_origin_x,           mount_origin_y + hole_dy, standoff_z, standoff_h, standoff_d, insert_d, insert_depth);
    standoff_heat_insert(mount_origin_x + hole_dx, mount_origin_y + hole_dy, standoff_z, standoff_h, standoff_d, insert_d, insert_depth);
}


// custom_tray_01(...)
// Public — example custom tray for a Raspberry Pi 5 with active cooler.
// Params:
// panel_u_size, tray_u_size, tray_depth_scale, holes: tray and panel sizing.
// post_width, front_panel_thickness, front_panel_undersizing, tray_thickness: geometry references for cutout and standoff placement.
// side_support, back_panel: structural options.
// import_file and import dimensions/offsets/mode: front face emboss/engrave.
// e.g. custom_tray_01();
/**
module custom_tray_01(
    panel_u_size = 1,
    tray_u_size = 0.75,
    tray_depth_scale = 1,
    holes = 2,
    side_support = 1,
    back_panel = 1,
    post_width = 15.875,
    front_panel_thickness = 3.0,
    front_panel_undersizing = 0.1,
    tray_thickness = 5.0,
    import_file = "raspberry-pi.svg",
    import_type = "svg",
    import_width = 16,
    import_height = 20,
    import_depth = 0.2,
    import_offset_x = 140,
    import_offset_z = 0,
    import_mode = "emboss"
) {
    difference() {
        blank_variable_tray(
            panel_u_size = panel_u_size,
            tray_u_size = tray_u_size,
            tray_depth_scale = tray_depth_scale,
            holes = holes,
            import_file = import_file,
            import_type = import_type,
            import_width = import_width,
            import_height = import_height,
            import_depth = import_depth,
            import_offset_x = import_offset_x,
            import_offset_z = import_offset_z,
            import_mode = import_mode,
            side_support = side_support,
            back_panel = back_panel,
            front_panel_thickness = front_panel_thickness,
            tray_thickness = tray_thickness,
            post_width = post_width,
            front_panel_undersizing = front_panel_undersizing
        );

        rpi5_io_cutout_left(
            cutout_x = post_width + 26,
            cutout_z = 8 + tray_thickness,
            cutout_w = 56,
            cutout_h = 18,
            clearance = 0.6,
            front_panel_thickness = front_panel_thickness
        );
    }

    rpi5_standoffs_left(
        mount_origin_x = post_width + 29.5,
        mount_origin_y = front_panel_thickness + 23,
        hole_dx = 49,
        hole_dy = 58,
        standoff_h = 6,
        standoff_d = 7.0,
        insert_d = 3.8,
        insert_depth = 4.5,
        front_panel_undersizing = front_panel_undersizing,
        tray_thickness = tray_thickness
    );

    translate([post_width + 14, front_panel_thickness + 9, front_panel_undersizing + tray_thickness]) {
        translate([40, 33, 7]) {
            rotate([90, 0, 270]) {
                color("blue") {
                    import("raspberry_pi_5_with_active_cooler.stl", convexity = 10);
                }
            }
        }
    }
}
**/

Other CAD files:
dell optiplex 3080.scad
intel dg45fg.scad
parts-optional/dell optiplex 3080.scad
parts-optional/flex_psu.scad
parts-optional/intel dg45fg.scad
parts-optional/keystone panel.scad
parts-optional/rack custom tray 01.scad
parts-optional/rpi5.scad
parts-optional/ugreen um106x.scad
parts/blank variable tray.scad
parts/honeycomb.scad
parts/odd_parts.scad
parts/rack defines.scad
parts/rack panels.scad
parts/rack posts.scad
parts/rack side panel.scad
rack parts.scad
rack posts.scad
rack side panel.scad
rack tray.scad
rpi5.scad
ugreen um106x.scad

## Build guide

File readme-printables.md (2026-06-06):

# Variable Width Rack Design

No longer are you stuck with a 10 inch rack or a 19 inch rack you cannot print parts for. This design is meant to be printable on large-format printers while still giving you properly supported trays.

Normal defaults are a 350 mm wide panel and a 330 mm deep tray, but the design is parametric and can be changed.

## What This Is

This is a fully parametric rack system built in OpenSCAD. I wanted something bigger than the usual mini-rack designs, printable on a Creality K2 Plus, and flexible enough to suit different equipment without redesigning every part from scratch.

One of the main design goals was fixing a common annoyance in small printed racks: trays that cannot be removed without dismantling the frame. In this design, trays slide into rear support channels so they can be removed far more easily.

If you like the design, you are welcome to buy me a coffee:

https://buymeacoffee.com/amead77

## Quick Overview

Below is an assembly overview showing some of what is possible. Everything is customizable.

1. Top header: an extra joining point added to the post for connecting to the top joiner. Optional, but useful for stability.
2. Top joiner: ties posts together at the top. You can use 4 or more posts. In my example I use 6. Support cones are optional, but recommended.
3. Half-U panel: spans across posts and helps secure top and bottom joins.
4. Bottom joiner: same idea as the top joiner.
5. Post join location: used to connect inner posts to the top and bottom joins so they are not floating.
6. Side panel: optional, and can use different patterns or a logo.

For my rack I used 6 posts. Four face forward and the rear 2 face backwards. Keep that in mind when choosing which side gets tray slide support.

Assembly overview

## Rear View

Rear view of assembly

## 8-Leg Version

Assembly with 8 legs

## Partially Built Rack

This shows my own rack in progress. I do have a tray for the Dell system, but had not printed it at the time of the photo.

Partially built rack

## Side Panel Example

You do not have to use a honeycomb pattern. There are several possible styles, and the logo/image is optional.

Side panel

---

## Design Goals

- Rear-slide tray support: trays slide into a slot in the rear post instead of bolting front and rear. That means trays can be removed without dismantling the rack.
- Fully parametric: dimensions, hole counts, heights, and clearances are driven by variables. Use the OpenSCAD Customizer instead of editing everything manually.
- Modular: mix single or double-wide posts, variable-height trays and panels, plus optional joiners.

---

## Parts

### Posts

Posts are the vertical rails of the rack. They can be generated in configurable U heights and in single or double-wide versions. A slide channel can be added to the left side, right side, both sides, or neither.

I strongly recommend double-wide posts with top and bottom headers, cones, and slide support.

Post

### Trays

Trays are available in fully variable sizes. The variable tray supports a rear panel option so it can act more like a drawer. Trays slide into the rear slot of the post for easy removal.

Trays do not need to be full depth. For example, using 0.25 gives a quarter-depth tray on the Y axis.

The main tray logic is in `parts/blank variable tray.scad`, while `parts-optional/intel dg45fg.scad` is a useful example of a custom tray using it.

Variable tray

### Panels

Flat front panels are available for blanking unused rack slots. There are 1/2U, 1U, and 2U styles.

The variable tray system can also create most panel styles and is generally the recommended approach because it is more customizable.

The half-U panel is especially useful for tying posts together when using headers.

Half-U panel

2U panel

### Footer and Header

Optional pieces added to the top and bottom of posts. They provide attachment points for joiners.

If you want front-to-rear support braces, I recommend including them.

### Joiners

Optional horizontal joiners connect the front posts to the rear posts through the footer and header pieces.

You are not limited to 4 posts. The joiners can support additional intermediate posts, which is useful for wider racks or more tray support points.

Top joiner

Base joiner

---

## Custom Trays

The file `parts-optional/intel dg45fg.scad` contains a tray I made for an older mini-ITX board. It includes:

- a mount for a FlexATX PSU
- screw holes for mini-ITX
- a rear panel option
- an LED hole in the front for drive activity
- a large round power button cutout
- engraved board and CPU text on the front panel
- reinforcement on the front panel
- rear reinforcement using a chamfered back panel to reduce support requirements

Mini-ITX tray

I strongly recommend making test pieces before committing to long prints. Even a short post section with tray slides and a matching tray sample is enough to check fit and tolerances.

Test print

When I print the full tray, I use the following approach:

- cut away non-critical areas in the slicer to reduce filament usage
- angle cutouts to avoid supports where possible
- print face down so the tray rails do not need supports
- print face down so front text can be done cleanly in a single layer change
- use a shallow rear panel with a 30 degree chamfer for reinforcement without heavy support material

That way, only the PSU mount and mini-ITX screw holes generally need supports.

Slicer example

Another custom tray is `parts-optional/ugreen um106x.scad`, which I use for:

- a 5-port switch
- 4 keystone inserts

Ugreen tray

---

## Usage

1. Open `rack parts.scad` in OpenSCAD.
2. Open the Customizer panel.
3. Select the part you want from the `part` dropdown.
4. Adjust the parameters to suit your needs.
5. Render with F6 and export to STL or 3MF.

Available part options include:

- `assembly` for a full preview
- `post` for a single post
- `base joiner` and `top joiner` for horizontal joiners
- `1U tray`, `2U tray`, and `variable tray`
- `halfUpanel`, `1U panel`, `2U panel`, and `variable panel`

### Key Parameters

- `post_u_height`: height of the post in U units
- `post_doublewide`: `0` for single-wide, `1` for double-wide
- `slide_side`: `0` none, `1` left, `2` right, `3` both
- `front_panel_height`: panel or tray height in U, including fractional values like `1.5`
- `front_panel_hole_count`: mounting holes per side
- `tray_side_height`: tray wall height in hole spacings
- `tray_back_panel`: `0` open tray, `1` rear panel included
- `footer_include` and `header_include`: include footer and header attachment pieces

### Hardware

The default design is based on M6 screws with M6 hex nuts. If you want different fasteners, adjust the hole and nut parameters in the SCAD files.

---

## File Structure

- `rack parts.scad`: main entry point for selecting and configuring parts
- `parts/rack posts.scad`: post geometry
- `parts/rack panels.scad`: panel geometry for 1/2U, 1U, and 2U panels
- `parts/blank variable tray.scad`: main tray and panel generator
- `parts-optional/intel dg45fg.scad`: example custom tray

The old `parts/rack defines.scad` file is effectively deprecated and kept only for reference. Default values were moved into function and module defaults during refactoring.

---

## Requirements

- OpenSCAD. The nightly builds are recommended over the old stable releases.
- A printer that can handle the size you want. For example, a Creality K2 Plus can handle 350 mm and a Prusa XL can handle 340 mm.

---

## License

This project is licensed under Creative Commons Attribution Non-Commercial, CC BY-NC.

Copyright 2026 Adam Mead

Any Raspberry Pi and Dell logos remain the property of their respective owners. They are included only to avoid missing file errors in the source project.

---

## Why I Made This

This picture is not my design, but I did print it, and it is the main reason I made this rack system instead.

The rack design that pushed me to make this

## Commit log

2026-05-03 added slides to 1U segments
    [330mm rack parts.scad]
2026-05-03 1U blank panel begin
    [330mm rack parts.scad]
2026-05-03 panel and cleanup
    [330mm rack parts.scad]
2026-05-03 currently working 1U and 0.5U, legs, supports
    [330mm rack defines.scad, 330mm rack feet.scad, 330mm rack parts.scad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]
2026-05-03 working better
    [330mm rack defines.scad, 330mm rack footer.3mf, 330mm rack header.3mf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]
2026-05-03 Remove non-SCAD assets and enforce SCAD/SVG-only tracking
    [330mm rack footer.3mf, 330mm rack header.3mf, 330mm rack post 1Udouble.3mf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]
2026-05-03 create basic custom tray
    [330mm rack custom tray 01.scad, 330mm rack defines.scad, 330mm rack parts.scad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]
2026-05-03 basic custom tray
    [330mm rack custom tray 01.scad]
2026-05-04 fixes, comments, readme
    [330mm rack custom tray 01.scad, 330mm rack defines.scad, 330mm rack parts.scad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]
2026-05-04 allow part length tray creation
    [330mm rack parts.scad, 330mm rack tray.scad]
2026-05-04 add join piece for inner legs, clean up some more.
    [330mm rack defines.scad, 330mm rack parts.scad, 330mm rack posts.scad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]
2026-05-05 initial ug tray
    [ugreen um106x.scad]
2026-05-05 building switch tray and improving variable tray
    [330mm rack parts.scad, 330mm rack tray.scad, ugreen um106x.scad]
2026-05-05 fixes to variable tray
    [330mm rack tray.scad, ugreen um106x.scad]
2026-05-05 further detachments from defines, refactor
    [330mm rack custom tray 01.scad, 330mm rack parts.scad, 330mm rack posts.scad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]
2026-05-05 final for the switch, next part will be adding keystones
    [ugreen um106x.scad]
2026-05-05 comments only
    [ugreen um106x.scad]
2026-05-06 update readme licence
    [ugreen um106x.scad]
2026-05-07 keystone fits, now to multiply
    [keystone panel.scad]
2026-05-07 switch panel and keystones complete maybe
    [keystone panel.scad, ugreen um106x.scad]
2026-05-08 various tray parts
    [330mm blank variable tray.scad, dell optiplex 3080.scad, rpi5.scad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]
2026-05-10 rpi5 panel
    [330mm rack parts.scad, keystone panel.scad, rpi5.scad]
2026-05-15 design mini-itx tray
    [intel dg45fg.scad]
2026-05-15 updates to allow variable width
    [330mm blank variable tray.scad, 330mm rack custom tray 01.scad, 330mm rack defines.scad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]
2026-05-15 size to 350
    [330mm rack parts.scad]
2026-05-16 depreciated blank_panel() in favour of just calling the tray function
    [blank variable tray.scad, dell optiplex 3080.scad, rack parts.scad]
2026-05-16 tray adj. more options
    [dell optiplex 3080.scad, rack parts.scad, ugreen um106x.scad]
2026-05-23 flex psu
    [blank variable tray.scad, flex_psu.scad, intel dg45fg.scad]
2026-05-24 readme, refactors, renames, photoes, mini-itx board
    [blank variable tray.scad, intel dg45fg.scad, odd_parts.scad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]
2026-05-24 adjust default sizing to be uniform
    [rack panels.scad]
2026-06-01 move files to sub dirs
    [blank variable tray.scad, dell optiplex 3080.scad, flex_psu.scad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]
2026-06-01 tify up customiser view. fix some paths
    [rack parts.scad]
2026-06-01 fix nut circle diameter, documentation
    [rack panels.scad, rack posts.scad]
2026-06-01 printables formatted readme
2026-06-06 moved to rpi
    [blank variable tray.scad, dell optiplex 3080.scad, flex_psu.scad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]
2026-06-06 update default widths
    [blank variable tray.scad]
2026-06-06 increased clearance
    [blank variable tray.scad, rack parts.scad, rack posts.scad]
2026-06-06 clearance adj.
    [blank variable tray.scad, rack parts.scad]
2026-06-06 panel / tray splitting
    [blank variable tray.scad, intel dg45fg.scad]
2026-06-06 more work on split
    [blank variable tray.scad, intel dg45fg.scad]
2026-06-06 tray/panel split working
    [blank variable tray.scad, intel dg45fg.scad]
2026-06-06 fix side 'oles positioning
    [blank variable tray.scad, intel dg45fg.scad]
2026-06-06 split model
    [intel dg45fg.scad]
2026-06-06 chamfer edges of split
    [blank variable tray.scad, intel dg45fg.scad]
2026-06-06 add chamfer to tray split base
    [blank variable tray.scad, intel dg45fg.scad]
2026-06-06 set chamfer tray for only split mode
    [blank variable tray.scad]
2026-06-08 adjust tolerances
    [rack posts.scad]
2026-06-08 fix tray creating lip when split print mode
    [blank variable tray.scad, intel dg45fg.scad]
2026-06-08 default to single side support per -U
    [blank variable tray.scad]
2026-06-08 documentation, tolerances
    [blank variable tray.scad]
2026-06-12 remove external lib req.
    [blank variable tray.scad]
2026-06-12 adjust tolerances, colour posts, fix merge. remove external lib reqs.
    [blank variable tray.scad, rack parts.scad, rack posts.scad]
